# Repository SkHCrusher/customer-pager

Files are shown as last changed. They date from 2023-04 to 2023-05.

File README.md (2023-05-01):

# Customer pager


You might know a customer pager from restaurants or similar places where several customers have to be packed into a mixed queue. With the customer pager this queue is virtualized.

The customer receives a pager with a number. This number is given out by the staff.
With this pager the customer can already sit down at his place. As soon as it is his turn, the staff can "call" the pager with a specific number.

The customer is alerted via the pager by vibration, display on the OLED and LEDs that it is his turn.

He brings the device back to the staff. The staff exchanges the device with the goods, deactivates the alarm and can use the pager for the next customer.

## Features

This system consists of a administration station(station for the employees) and several clients/pagers for the customers.

- :pager: Based on an ESP32
- :signal_strength: Communication via the existing Wifi
- :high_brightness: OLED display with 128x32 pixels
- :battery: Integrated battery incl. charging function via base
- :flashlight: Attention through flashing LEDs and vibration
- :pencil2: Easy configuration via WifiManager
- :satellite: REST API for easy integration into your own system

## General

### Configure Arduino IDE

The client and also the administration station are based on the LOLIN32 Lite and need the right package for the Arduino IDE.

Install (if not already done) via the Arduino Board Manager the "esp32" package from "Espressif Systems".

After the package has been installed, you will find the appropriate board under "WEMOS LOLIN32 Lite".

### 3D printing files

You can find all the necessary 3D printing files on the following page for free download:
https://www.printables.com/model/467464-customer-pager

Here you will find all print data for the client, administration station and the charging station including Fusion360 original file for any adjustments.

## Client

The client is the hardware that the customer gets. 

As soon as it is his turn, the client vibrates and flashes its LEDs.
Once the customer brings the client back to the issuance, this can stop the alarm and give him in exchange, for example, the goods.

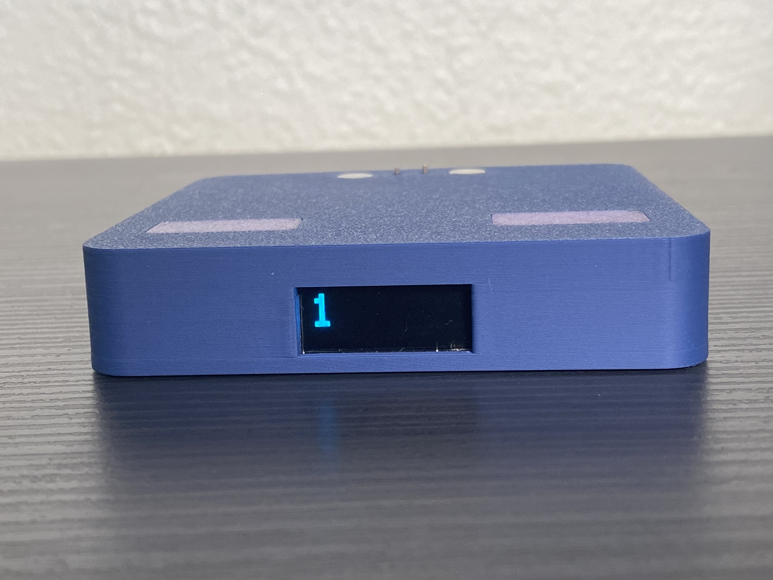
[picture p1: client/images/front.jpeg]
front image
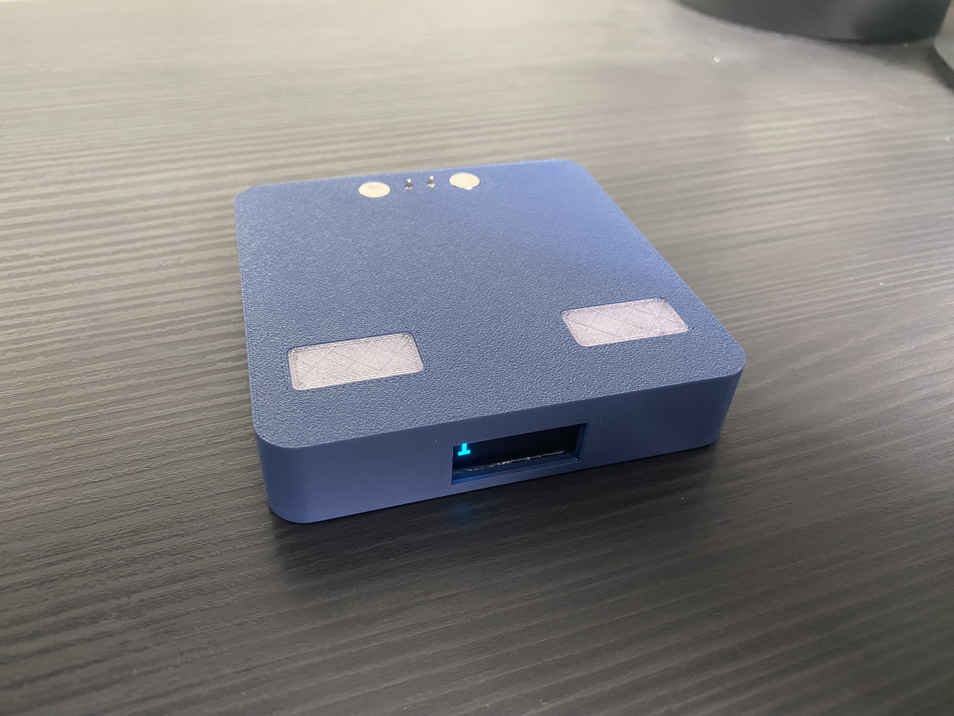
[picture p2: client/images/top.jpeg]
top image
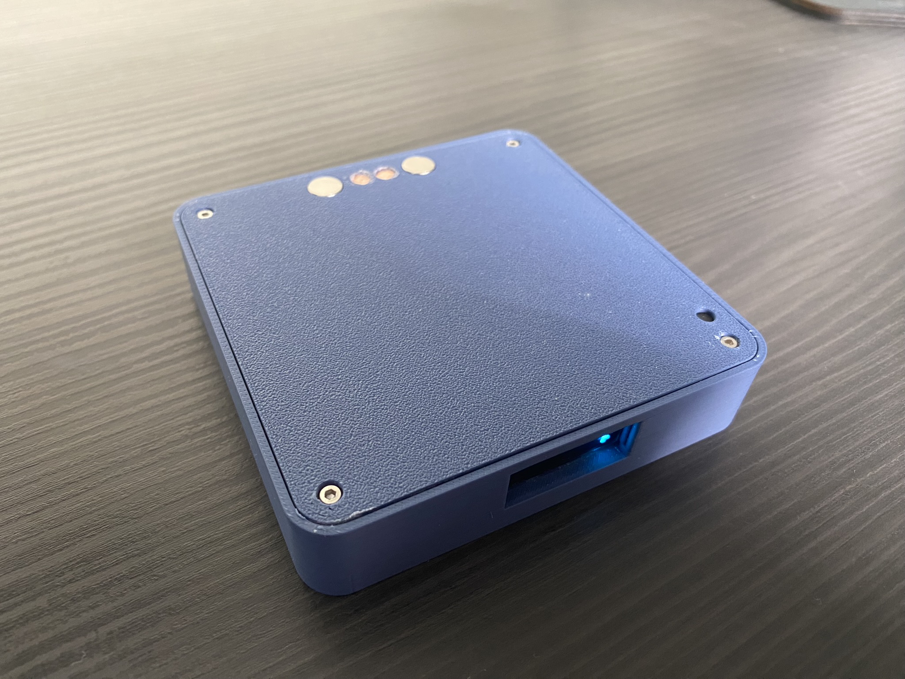
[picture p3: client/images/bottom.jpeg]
bottom image
|  |  |  |
| --- | --- | --- |

### Hardware

#### Componets

Below I list all the components I needed to build the client. The store links are only for reference. All goods can also be bought at any other dealer:

| Name | Menge | Shop-Link |
| --- | ----- | --- |
| LOLIN32 Lite Development Board | 1 | https://www.amazon.de/dp/B07MC4Y73P |
| I2C OLED Display 0,91" 128X32 Pixel | 1 | https://www.amazon.de/dp/B09BFK48GJ |
| 3.7V 820mAh Lipo Battery | 1 | https://www.amazon.de/dp/B082152887 |
| Vibration motor 3.7V | 1 | https://www.amazon.de/dp/B083Y1BFYQ |
| LED white 3mm | 2 | https://www.amazon.de/dp/B01AUI4VR4 |
| USB Micro Port Plug | 1 | https://www.amazon.de/dp/B09ZRHXRNR |
| Push button 6x6 | 1 | https://www.amazon.de/dp/B08VDFW4VG |
| Pogo Pin Connector | 2 | https://www.amazon.de/dp/B07FPCPX8X |
| Copper rivets | 2 | https://www.amazon.de/dp/B018HMGM54 |
| 10k resistor | 1 | https://www.amazon.de/dp/B08QRJZ82J |
| Ruthex M2 thread insert | 4 | https://www.amazon.de/dp/B088QJG676 |
| Magnets 8 x 2 mm | 4 | https://www.amazon.de/dp/B0BLCFSZKZ |

In addition to these components, cables, soldering accessories, cable ties, etc. are needed, which I have not listed here.

#### Wiring

The wiring of the components is done as shown in this diagram:

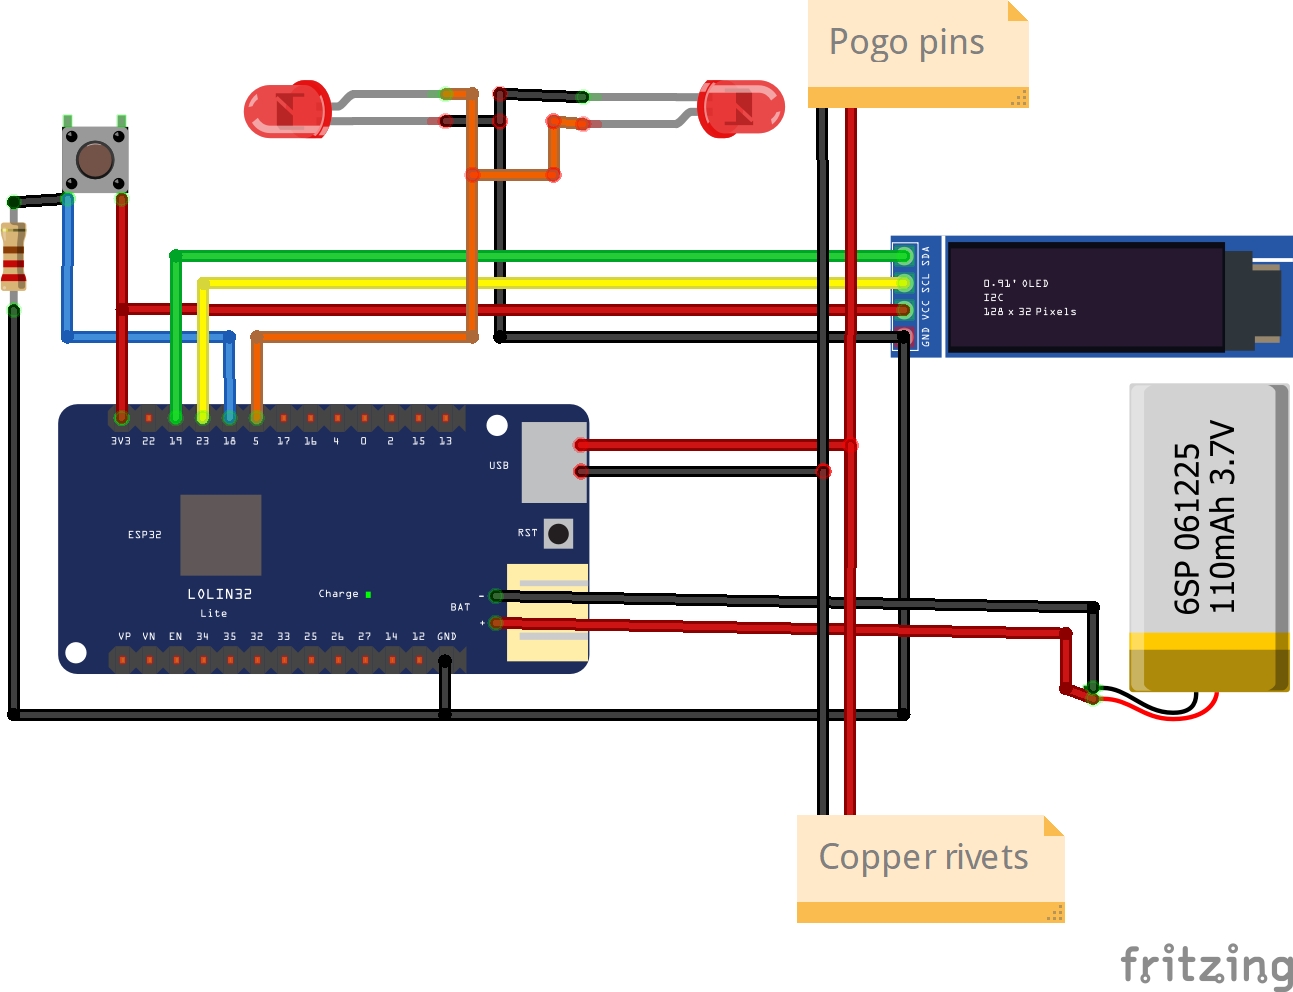
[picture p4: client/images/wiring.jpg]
wiring diagram
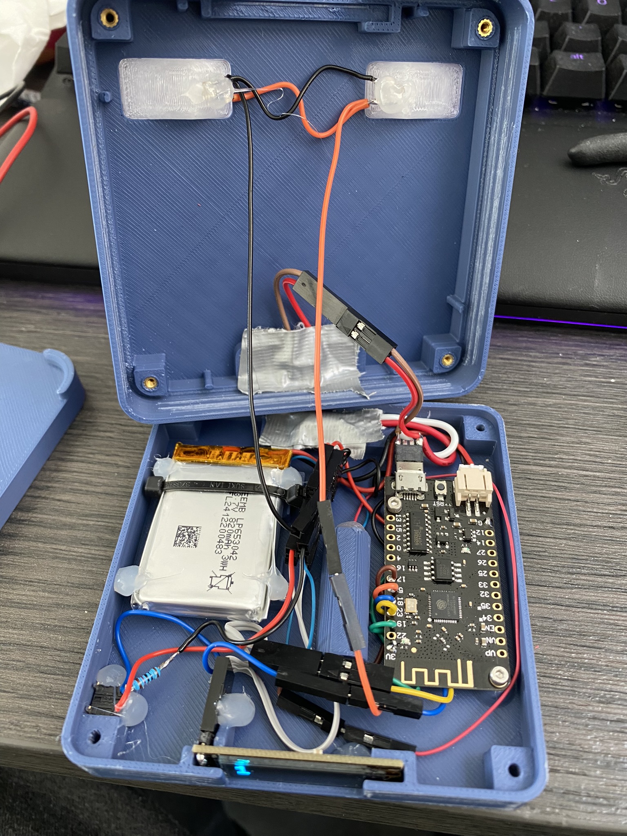
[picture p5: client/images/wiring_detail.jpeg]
front image
|  |  |
| --- | --- |

Here the pinout again in detail:

| Pin  | Name |
| ---- | --- |
| 5 | LEDs |
| 17 | Vibration |
| 18 | Button |
| 19 | OLED SDA  |
| 23 | OLED SCL  |

**Important:** Please only pay attention to the correct polarity of the magnets and the current!

### Software

Download the folder under "client/arduino-code/" locally and open it in your Arduino IDE.

#### Required libraries

The following libraries must additionally be installed. They can all be installed via the Arduino Library or manually from GitHub:

| Name | Autor | GitHub | Webseite |
| --- | --- | --- | --- |
| EasyButton | Evert Arias | https://github.com/evert-arias/EasyButton | https://easybtn.earias.me/ |
| Adafruit_GFX | Adafruit | https://github.com/adafruit/Adafruit-GFX-Library | |
| Adafruit_SSD1306 | Adafruit | https://github.com/adafruit/Adafruit_SSD1306 | |
| WiFiManager | tzspu | https://github.com/tzapu/WiFiManager | |

#### Installation

Please note that you need the package for the LOLIN32 board first. The procedure is described under "[General > Configure Arduino IDE](#configure-arduino-ide)".

Connect the LOLIN32 Lite via USB to your computer and select the correct COM port and as device "WEMOS LOLIN32 Lite".
Then upload the source code directly via your Arduino Librabry using "Sketch > Upload".

### How to use

After starting the WifiManager automatically opens a WLAN network with the name "CustomerPager".
Connect to this and set up the WLAN via the configuration menu that appears and finally the pager number under "Setup".

After the Wifi is set up, the client provides a REST API for the required functions. The port of the REST interface is 8080.

The following endpoints are provided:

| Endpunkt | Beschreibung | Beispiel |
| --- | --- | --- |
| GET /alarm-start | Starts the alarm for this pager | http://192.168.0.2:8080/alarm-start |
| GET /alarm-stop  | Stops the alarm for this pager  | http://192.168.0.2:8080/alarm-stop  |

## Charging station

The charging station focuses on exactly one feature - charging the pagers. No other gimmicks  - pure focus on charging.

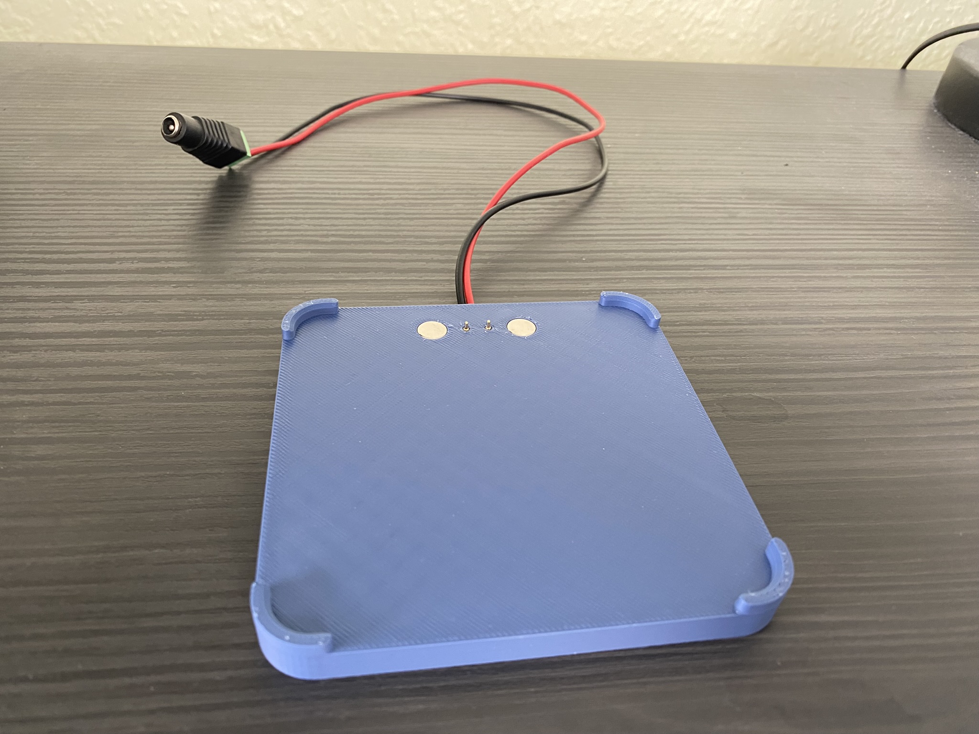
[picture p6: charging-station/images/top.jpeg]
top image of the charging station
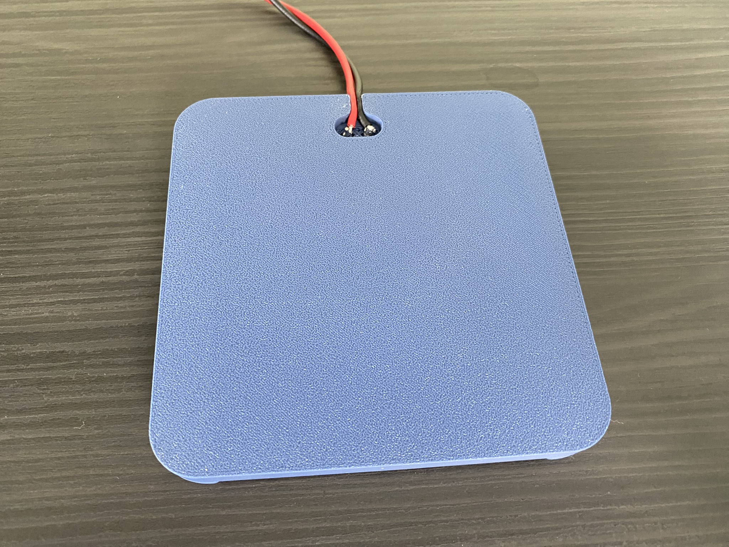
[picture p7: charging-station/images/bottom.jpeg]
bottom image of the charging station
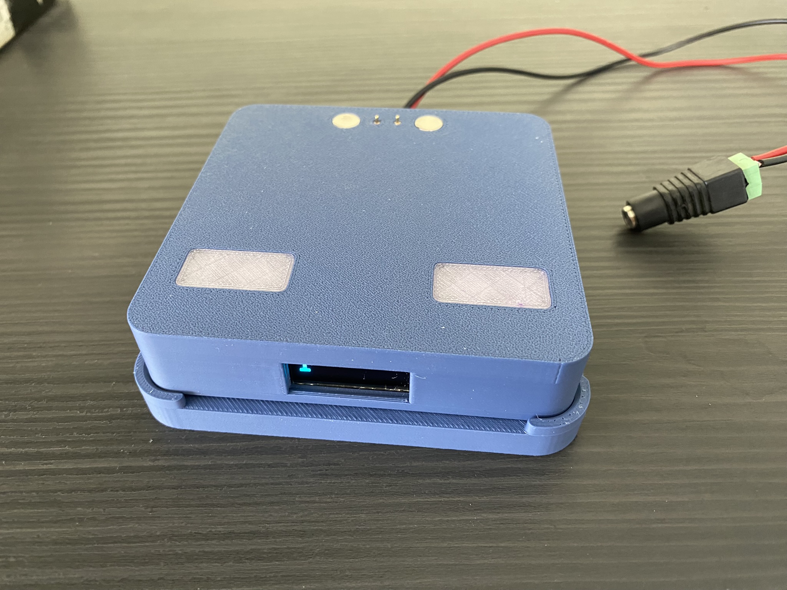
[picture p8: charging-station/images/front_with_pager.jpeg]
front image of the charging station with pager
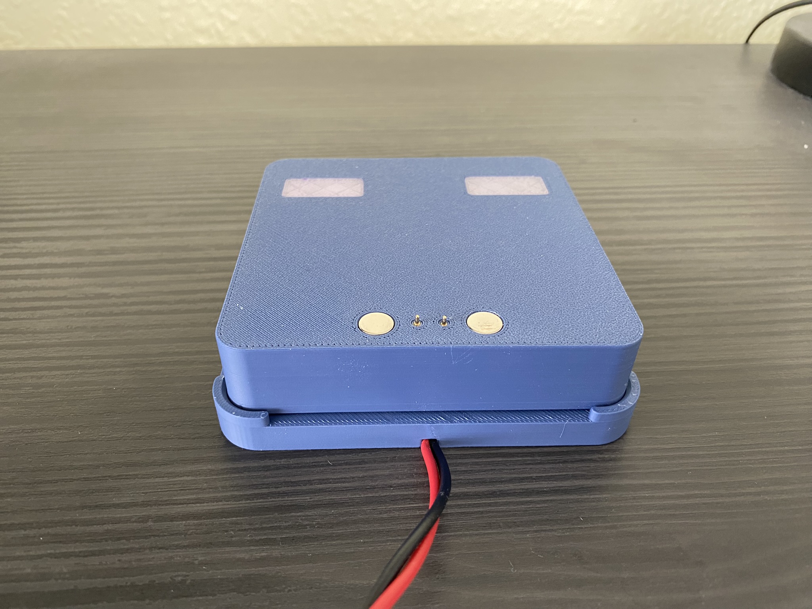
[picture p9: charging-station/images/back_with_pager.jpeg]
back image of the cgarging station with pager
|  |  |  |  |
| --- | --- | --- | --- |

### Hardware

#### Componets

Below I list all the components I needed to build the charging station. The store links are only for reference. All goods can also be bought at any other dealer:

| Name | Menge | Shop-Link |
| --- | ----- | --- |
| Pogo Pin Connector | 2 | https://www.amazon.de/dp/B07FPCPX8X |
| Magnets 8 x 2 mm | 2 | https://www.amazon.de/dp/B0BLCFSZKZ |

#### Wiring

The charging station is quite simple. Here you only have to solder the cables of the power supply to one pogo pin each.

**Important:** Please only pay attention to the correct polarity of the magnets and the current!

## Administration Station

coming soon

## ToDos

Currently, all to-dos for this project are collected here: [Customer pager ToDo's](https://github.com/users/SkHCrusher/projects/2)

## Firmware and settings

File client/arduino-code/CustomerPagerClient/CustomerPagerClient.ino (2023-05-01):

/**
 * Customer pager - Client
 * 
 * An ESP32 based customer pager with OLED display, 
 * vibration, LED lights and charging function.
 * 
 * @author Tobias Stewen
 * @version 1.0.0
 * @license MIT
 * @url https://github.com/SkHCrusher/customer-pager
 */
#include <EasyButton.h>
#include <SPI.h>
#include <Wire.h>
#include <Adafruit_GFX.h>
#include <Adafruit_SSD1306.h>
#include <WiFiManager.h>
#include <Preferences.h>

// Generell
bool pagerActive = false;
unsigned long currentTime = 0; 

// Number
int pagerNumber;
unsigned long currentIdleMoveTime = 0; 
unsigned int idleMoveTime = 4000;

// Display
#define SCREEN_WIDTH 128
#define SCREEN_HEIGHT 32
#define OLED_RESET     -1
#define SCREEN_ADDRESS 0x3C
Adafruit_SSD1306 display(SCREEN_WIDTH, SCREEN_HEIGHT, &Wire, OLED_RESET);

// Alarm-Icon
const int alarmIconSwitchTime = 400;
int currentAlarmIconFrame = 0; 
unsigned long lastAlarmIconTime = 0; 

// Bitmaps converted by http://javl.github.io/image2cpp/
// 'AlarmOn_26x26'
const unsigned char epd_bitmap_AlarmOn_26x26 [] PROGMEM = {
	0x1c, 0x00, 0x0e, 0x00, 0x38, 0x00, 0x07, 0x00, 0x60, 0x00, 0x01, 0x80, 0xc6, 0x00, 0x18, 0xc0, 
	0xcc, 0x00, 0x0c, 0xc0, 0x98, 0x00, 0x06, 0x40, 0x10, 0xff, 0xc2, 0x00, 0x01, 0x00, 0x20, 0x00, 
	0x02, 0x00, 0x10, 0x00, 0x02, 0x00, 0x10, 0x00, 0x3f, 0xff, 0xff, 0x00, 0x40, 0x00, 0x00, 0x80, 
	0x80, 0x00, 0x00, 0x40, 0x80, 0x00, 0x00, 0x40, 0xb9, 0xc4, 0xed, 0x40, 0xa9, 0x0e, 0x95, 0x40, 
	0xb9, 0xca, 0x96, 0x40, 0xa9, 0x1e, 0xb2, 0x40, 0xad, 0xd2, 0xe2, 0x40, 0x80, 0x00, 0x00, 0x40, 
	0x80, 0x00, 0x00, 0x40, 0x40, 0x00, 0x00, 0x80, 0x3f, 0xff, 0xff, 0x00, 0x09, 0x00, 0x12, 0x00, 
	0x09, 0x00, 0x12, 0x00, 0x06, 0x00, 0x0c, 0x00
};
// 'AlarmOff_26x26'
const unsigned char epd_bitmap_AlarmOff_26x26 [] PROGMEM = {
	0x00, 0x00, 0x00, 0x00, 0x00, 0x00, 0x00, 0x00, 0x00, 0x00, 0x00, 0x00, 0x00, 0x00, 0x00, 0x00, 
	0x00, 0x00, 0x00, 0x00, 0x00, 0x00, 0x00, 0x00, 0x00, 0xff, 0xc0, 0x00, 0x01, 0x00, 0x20, 0x00, 
	0x02, 0x00, 0x10, 0x00, 0x02, 0x00, 0x10, 0x00, 0x3f, 0xff, 0xff, 0x00, 0x40, 0x00, 0x00, 0x80, 
	0x80, 0x00, 0x00, 0x40, 0x80, 0x00, 0x00, 0x40, 0xb9, 0xc4, 0xed, 0x40, 0xa9, 0x0e, 0x95, 0x40, 
	0xb9, 0xca, 0x96, 0x40, 0xa9, 0x1e, 0xb2, 0x40, 0xad, 0xd2, 0xe2, 0x40, 0x80, 0x00, 0x00, 0x40, 
	0x80, 0x00, 0x00, 0x40, 0x40, 0x00, 0x00, 0x80, 0x3f, 0xff, 0xff, 0x00, 0x09, 0x00, 0x12, 0x00, 
	0x09, 0x00, 0x12, 0x00, 0x06, 0x00, 0x0c, 0x00
};

// Array of all bitmaps for convenience. (Total bytes used to store images in PROGMEM = 256)
const int epd_bitmap_allArray_LEN = 2;
const unsigned char* epd_bitmap_allArray[2] = {
	epd_bitmap_AlarmOff_26x26,
	epd_bitmap_AlarmOn_26x26
};

// Button - Blue
const int buttonPin = 18; 
int buttonWifiManagerPresses = 3;
int buttonWifiManagerTimeout = 1000;
const unsigned long buttonPressTime = 1000; 
EasyButton button(buttonPin, 35, true, false);

// LED - Orange
const int ledPin = 5;
const int ledSwitchTime = 200;
bool currentLedState = false; 
unsigned long lastLedTime = 0; 

// Vibration - Brown
const int vibrationPin = 17;
const int vibrationDelay = 800;
bool currentVibrationState = false; 
unsigned long lastVibrationTime = 0; 

// Wifi
WiFiManager wm;
int wifiConfigurationPortalTimeout = 60;
char wifiName[32] = "CustomerPager";
char wifiPassword[32] = "password";
char tempPagerNumber[3];
WiFiManagerParameter custom_pager_number("pager_number", "Pager Number", "", 3);

// Webserver
WebServer server(8080);

// Config
Preferences preferences;

void setup() {
  Serial.begin(115200);

  // Default values
  currentTime = millis();
  currentIdleMoveTime = currentTime;
  pagerActive = false;

  // Config
  loadConfig();

  // Display - Yellow/Green
  Wire.begin(23, 19);
  if(!display.begin(SSD1306_SWITCHCAPVCC, SCREEN_ADDRESS)) {
    Serial.println(F("SSD1306 allocation failed"));
    for(;;); // Don't proceed, loop forever
  }
  displayWifiConnection();
  
  // LED
  pinMode(ledPin, OUTPUT);
  
  // Vibration
  pinMode(vibrationPin, OUTPUT);
  
  // Button
  button.begin();
  button.onPressedFor(buttonPressTime, onPressedForDuration);
  button.onSequence(buttonWifiManagerPresses, buttonWifiManagerTimeout, onActivateWifiManager);

  // Wifi
  wifiSetup();
}

void loop() {
  currentTime = millis();

  button.read();
  alarmLoop();
  displayLoop();
  server.handleClient();
}

void loadConfig() {
  preferences.begin("pager-data", true);
  pagerNumber = preferences.getUInt("pagernumber", 0);
  preferences.end();
}

void apiAlarmStart() {
  activateAlarm();
  server.send(200, "text/plain", "Alarm accepted");
}

void apiAlarmStop() {
  deactivateAlarm();
  server.send(200, "text/plain", "Alarm accepted");
}

void wifiSetup() {
  // Add Customparameter and set default value
  wm.addParameter(&custom_pager_number);
  char tmpChar[3];
  itoa(pagerNumber, tmpChar, 10);
  custom_pager_number.setValue(tmpChar, 3);

  // Custom menu
  // Added param for custom configuration
  // Added exit to start loop after configuration
  std::vector<const char *> menu = {"wifi","info","param","close","sep","update","exit"};
  wm.setMenu(menu);

  // Setup Callback
  wm.setSaveParamsCallback(saveWifiParamsCallback);

  // Custom Routes
  //wm.setWebServerCallback(bindServerCallback);

  // Init Wifi
  bool res;
  res = wm.autoConnect(wifiName, wifiPassword);
  if(!res) {
    ESP.restart();
  }

  // Start new Webserver
  Serial.println("Custom Webserver");
  
  server.on("/alarm-start", apiAlarmStart);
  server.on("/alarm-stop", apiAlarmStop);
  server.begin();
}

void saveWifiParamsCallback () {
  int newPagerNumber = atoi(custom_pager_number.getValue());
  pagerNumber = newPagerNumber;

  preferences.begin("pager-data", false);
  preferences.putUInt("pagernumber", pagerNumber);
  preferences.end();

  wm.stopConfigPortal();
}

void onPressedForDuration() {
  if (pagerActive) {
    deactivateAlarm();
    return;
  }

  activateAlarm();
}

void onActivateWifiManager() {
  displayWifiConnection();
  wm.setConfigPortalTimeout(wifiConfigurationPortalTimeout);
  wm.startConfigPortal(wifiName, wifiPassword);
}

void activateAlarm() {
  pagerActive = true;
  currentVibrationState = true;
  lastVibrationTime = currentTime;
}

void deactivateAlarm() {
  pagerActive = false;
  currentVibrationState = false;
  currentIdleMoveTime = 0;
  currentIdleMoveTime = currentTime;
}

void displayWifiConnection() {
  display.clearDisplay();
  display.setTextSize(1);
  display.setTextColor(SSD1306_WHITE);

  display.setCursor(0, 0);
  display.println("Configure Wifi!");
  display.setCursor(0, 8);
  display.println("Networkname:");
  display.setCursor(0, 16);
  display.println(wifiName);

  display.display();
}

void displayLoop() {
  // Prepare
  display.clearDisplay();
  display.setTextSize(4);
  display.setTextColor(SSD1306_WHITE);

  // Pager number
  int numberPosX = 0;
  int maxPosX = 128 - ((1 + floor(log10(pagerNumber))) * 24);

  // Animate number while idle to prevent burn-in
  if (!pagerActive) {
    unsigned int timeDiff = currentTime - currentIdleMoveTime;

    // Reset if to old
    if (timeDiff > idleMoveTime) {
      currentIdleMoveTime = currentTime;
    }

    // Check direction
    if (timeDiff <= (idleMoveTime / 2)) {
      // Right
      numberPosX = map(timeDiff, 0, (idleMoveTime / 2), 0, maxPosX);
    } else {
      // Left
      numberPosX = map(timeDiff, ((idleMoveTime / 2) + 1), idleMoveTime, maxPosX, 0);
    }
  }

  // Print number on correct position
  display.setCursor(numberPosX, 0);
  display.println(pagerNumber);

  // Alarm Icon
  if (pagerActive) {
    if ((lastAlarmIconTime + alarmIconSwitchTime) < currentTime) {
      currentAlarmIconFrame = (currentAlarmIconFrame == 0) ? 1 : 0;
      lastAlarmIconTime = currentTime;
    }
    
    display.drawBitmap(102, 0, epd_bitmap_allArray[currentAlarmIconFrame], 26, 26, SSD1306_WHITE);
  }

  // Update display
  display.display();
}

void alarmLoop() {
  if (pagerActive) {
    // Vibration
    if ((lastVibrationTime + vibrationDelay) < currentTime) {
      currentVibrationState = !currentVibrationState;
      lastVibrationTime = currentTime;
    }

    if (currentVibrationState) {
      digitalWrite(vibrationPin, HIGH);
    } else {
      digitalWrite(vibrationPin, LOW);
    }

    // LED
    if ((lastLedTime + ledSwitchTime) < currentTime) {
      currentLedState = !currentLedState;
      lastLedTime = currentTime;
    }

    if (currentLedState) {
      digitalWrite(ledPin, HIGH);
    } else {
      digitalWrite(ledPin, LOW);
    }
  } else {
    // Vibration Off
    digitalWrite(vibrationPin, LOW);

    // LED Off
    digitalWrite(ledPin, LOW);
  }
}

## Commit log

2023-04-30 Client Arduino code
2023-04-30 Wiring file with Frizing Software + exported image
    [wiring.fzz]
2023-04-30 Update readme with wiring
2023-05-01 Update how to use and new wiring detail image
2023-05-01 Remove (problem with upper case ending)
2023-05-01 add (problem with upper case ending)
2023-05-01 Charging station images
2023-05-01 Added information for the charging station
2023-05-01 add header, correct color names and add idle movement to prevent burn-in
    [CustomerPagerClient.ino]
2023-05-01 Arduino build for direct upload + gitignore for needed files

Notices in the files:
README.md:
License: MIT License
